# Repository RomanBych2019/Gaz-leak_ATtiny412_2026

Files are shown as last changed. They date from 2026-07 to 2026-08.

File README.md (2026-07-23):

# Контроллер датчика газа на ATtiny412

Назначение выводов:

- PA0: UPDI
- PA1: светодиод состояния платы
- PA2: вход АЦП датчика с внешней подтяжкой 4.7 кОм к GND
- PA3: отладочный TX, программный UART 2400 бод
- PA6: выход силового ключа 2
- PA7: выход силового ключа 1

Основная логика:

- после прогрева выполняется первоначальная калибровка чистого воздуха;
- новое значение сравнивается с сохраненным в EEPROM: если разница не больше допустимой, оно применяется и записывается; если разница большая, используется сохраненное значение;
- обрыв датчика или замыкание линии на GND определяется по АЦП около 0 В;
- замыкание выхода датчика на питание определяется по АЦП около +5 В;
- состояние ALARM защелкивается до перезапуска питания контроллера;
- остальные состояния являются восстанавливаемыми.

Автокалибровку можно отключить на этапе компиляции в `src/main.cpp`:

```cpp
#define AUTOCALIBR 0
```

При отключенной автокалибровке используются фиксированные заводские пороги АЦП.

Для выбора поведения PA6/PA7 измените `SENSOR_MODIFICATION` в `src/main.cpp`.

Варианты сборки:

- `attiny412`: распиновка базовой платы;
- `attiny412_lin`: распиновка платы с LIN-драйвером, сборка с `LIN_DRIVER`.

Сборка:

```sh
pio run -e attiny412
pio run -e attiny412_lin
```

Прошивка:

Проект использует `serialupdi`. Скорость загрузки задана в `platformio.ini`:
`upload_speed = 19200`.

Обычная версия:

```sh
pio run -e attiny412 -t upload
```

LIN-версия:

```sh
pio run -e attiny412_lin -t upload
```

Если программатор не определяется автоматически, укажите порт в `platformio.ini`:

```ini
upload_port = /dev/cu.usbserial-4
```

LIN-вариант:

- трансивер: TLIN2029ADRBRQ1;
- скорость обмена: 19200 бод;

- PA0: UPDI
- PA1: LIN TXD
- PA2: LIN RXD 
- PA3: светодиод состояния платы/отладочный TX, программный UART 2400 бод
- PA6: вход АЦП датчика с внешней подтяжкой 4.7 кОм к GND
- PA7: выход силового ключа

- статусный кадр: LIN ID `0x12`, PID `0x92`, enhanced checksum;
- данные ответа: `state`, `flags`, `adc_l`, `adc_h`;
- `flags`: bit0 = ALARM защелкнут, bit1 = выход PA7 активен, bit2 = неисправность датчика, bit3 = прогрев.

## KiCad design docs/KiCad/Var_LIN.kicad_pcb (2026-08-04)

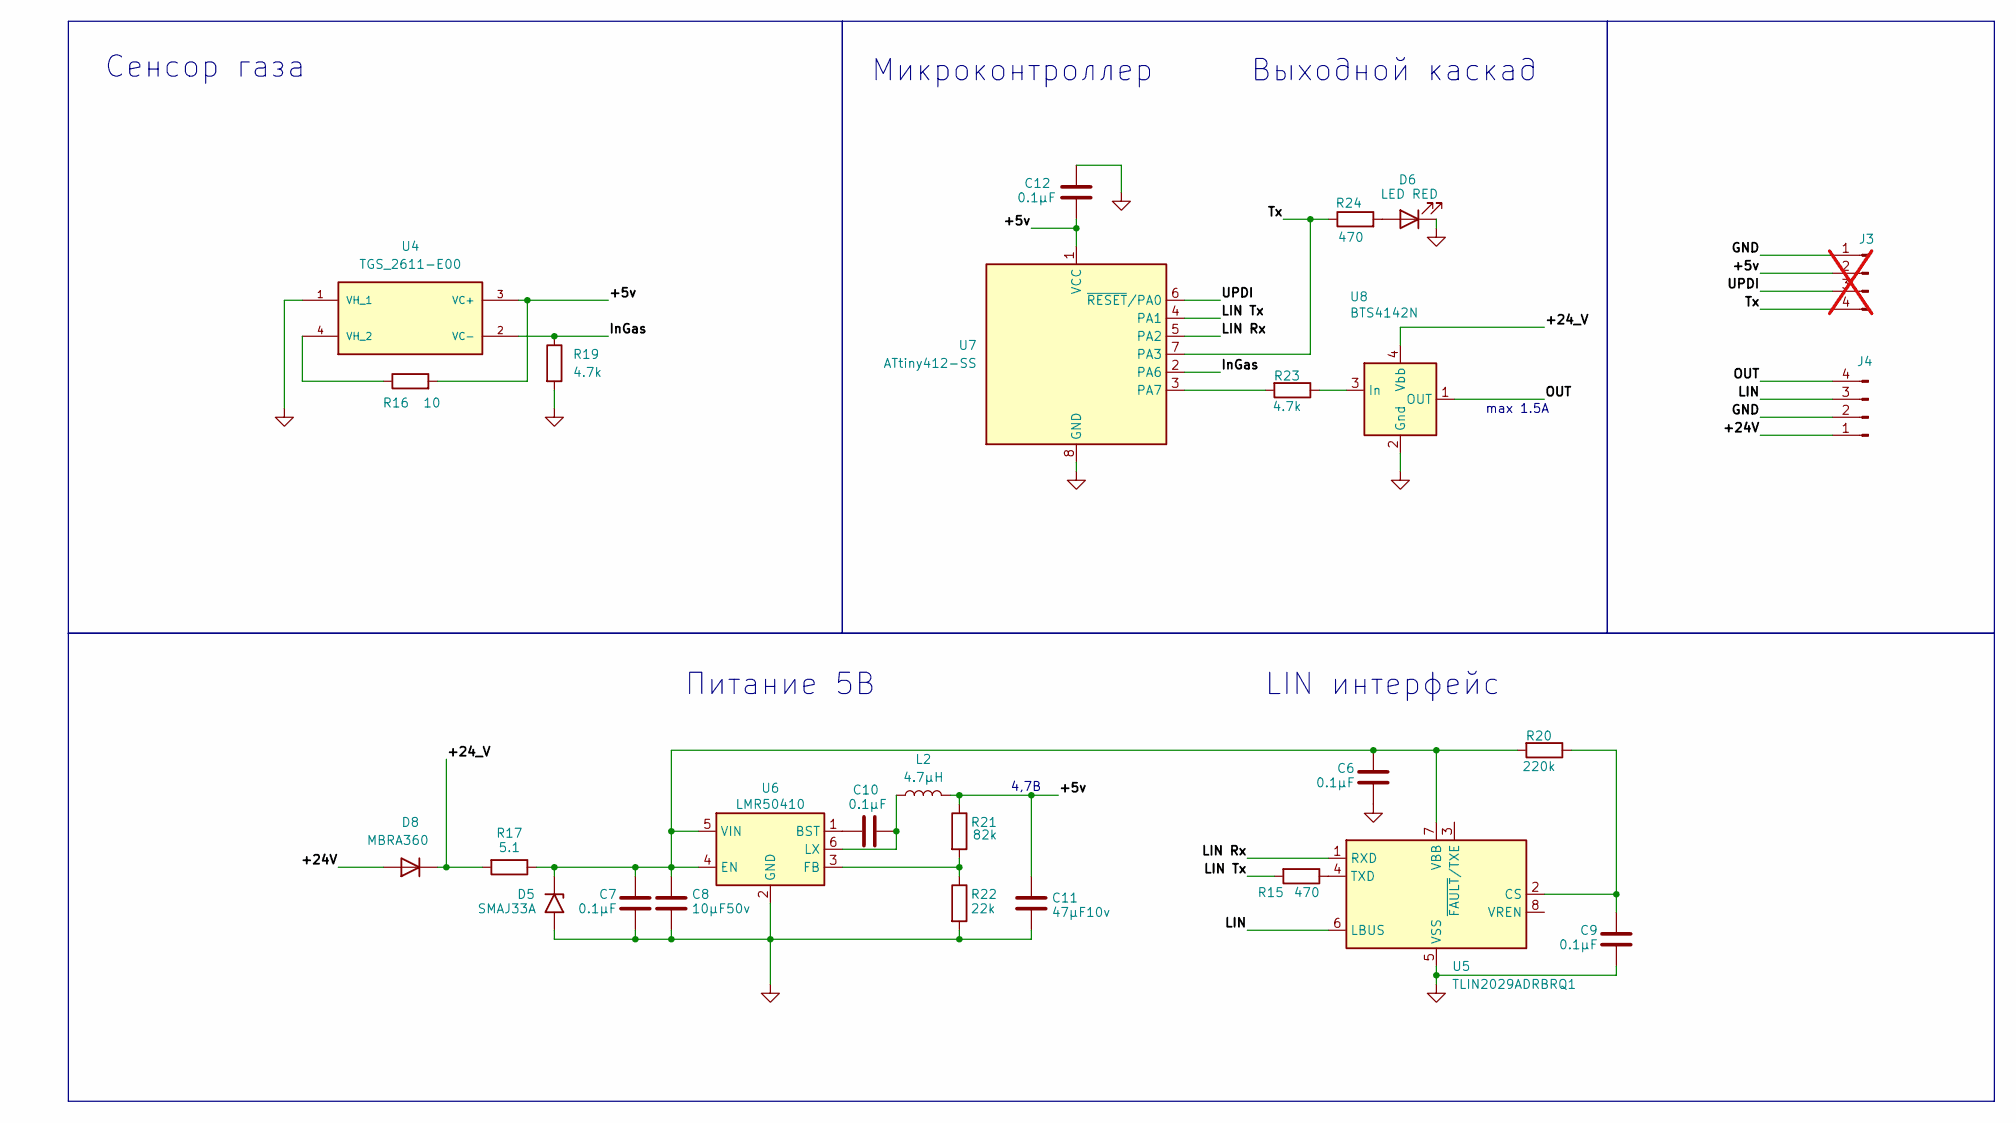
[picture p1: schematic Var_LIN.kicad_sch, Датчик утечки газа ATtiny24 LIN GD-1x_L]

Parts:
C6, C7, C9, C10, C12: 0.1µF; C_0603_1608Metric
C8: 10µF50v; C_0805_2012Metric
C11: 47µF10v; C_0805_2012Metric
D5: SMAJ33A; D_SMA
D6: LED RED; LED_0805_2012Metric
D8: MBRA360; D_SMA
J3: Conn_01x04_Pin; PinHeader_1x04_P1.27mm_Vertical; not fitted
J4: Conn_01x04_Pin; AMP SEAL 3.00mm_4p
L2: 4.7µH; L_1210_3225Metric
R15, R24: 470; R_0603_1608Metric
R16: 10; R_0805_2012Metric
R17: 5.1; R_1206_3216Metric
R19, R23: 4.7k; R_0603_1608Metric
R20: 220k; R_0603_1608Metric
R21: 82k; R_0603_1608Metric
R22: 22k; R_0603_1608Metric
U4: TGS_2611-E00; TO180P920X780-4P; PARTREV 0718
U5: TLIN2029ADRBRQ1; VSON-8-1EP_3x3mm_P0.65mm_EP1.65x2.4mm
U6: LMR50410; SOT-23-6
U7: ATtiny412-SS; SOIC-8_3.9x4.9mm_P1.27mm
U8: BTS4142N; SOT-223

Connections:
/+5v: C11.1, C12.2, J3.2, L2.2, R16.2, R21.1, U4.3 (VC+), U7.1 (VCC)
/+24V: D8.2 (A), J4.1; also elsewhere on the board
/+24_V: D8.1 (K), R17.2, U8.4 (Vbb)
/InGas: R19.1, U4.2 (VC-), U7.2 (PA6)
/LIN: J4.3, U5.6 (LBUS); also elsewhere on the board
/LIN Rx: U5.1 (RXD), U7.5 (PA2)
/LIN Tx: R15.2, U7.4 (PA1)
/OUT: J4.4, U8.1 (OUT), U8.5 (OUT); also elsewhere on the board
/Tx: J3.4, R24.1, U7.7 (PA3)
/UPDI: J3.3, U7.6 (~RESET/PA0)
GND: C6.2, C7.2, C8.2, C9.2, C11.2, C12.1, D5.2 (A2), D6.1 (K), J3.1, J4.2, R19.2, R22.2, U4.1 (VH_1), U5.5 (VSS), U6.2 (GND), U7.8 (GND), U8.2 (Gnd); also elsewhere on the board
unnamed: C6.1, C7.1, C8.1, D5.1 (A1), R17.1, R20.2, U5.7 (VBB), U6.4 (EN), U6.5 (VIN)
unnamed: D6.2 (A), R24.2
unnamed: R16.1, U4.4 (VH_2)
unnamed: C9.1, R20.1, U5.2 (CS)
unnamed: R15.1, U5.4 (TXD)
unnamed: C10.2, U6.1 (BST)
unnamed: R21.2, R22.1, U6.3 (FB)
unnamed: C10.1, L2.1, U6.6 (LX)
unnamed: R23.2, U7.3 (PA7)
unnamed: R23.1, U8.3 (In)

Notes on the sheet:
Сенсор газа
max 1.5A
4,7В
Микроконтроллер Выходной каскад
Питание 5В LIN интерфейс

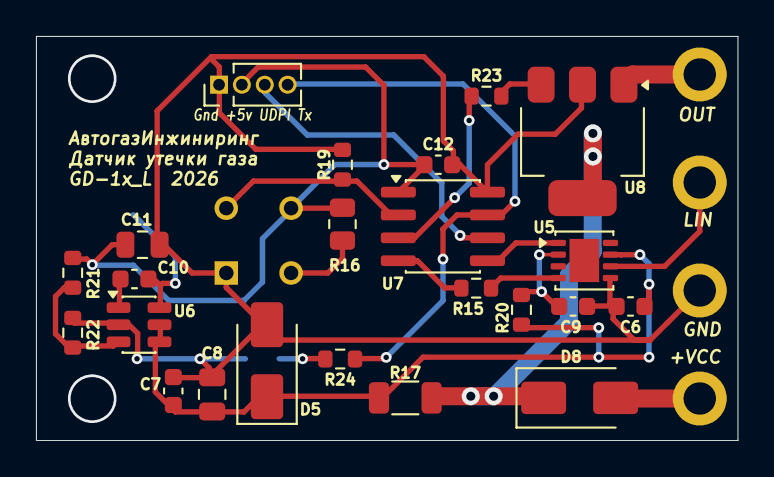
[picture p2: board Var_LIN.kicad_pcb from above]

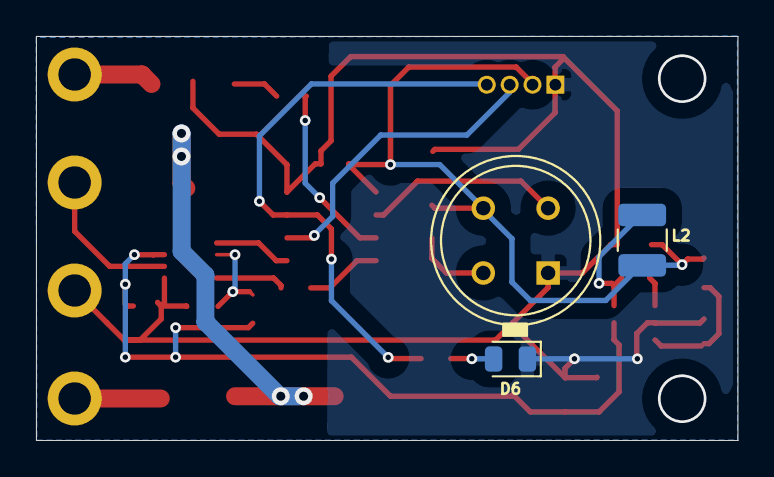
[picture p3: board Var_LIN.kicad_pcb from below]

Board: 2 copper layers, 39.0 x 22.4 mm, 27 parts (3 on the bottom side), 21 nets.

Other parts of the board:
J2: Conn_01x04_Pin; AMP SEAL 3.00mm_4p

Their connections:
/+24V: J2.1; also elsewhere on the board
/LIN: J2.3; also elsewhere on the board
/OUT: J2.4; also elsewhere on the board
GND: J2.2; also elsewhere on the board

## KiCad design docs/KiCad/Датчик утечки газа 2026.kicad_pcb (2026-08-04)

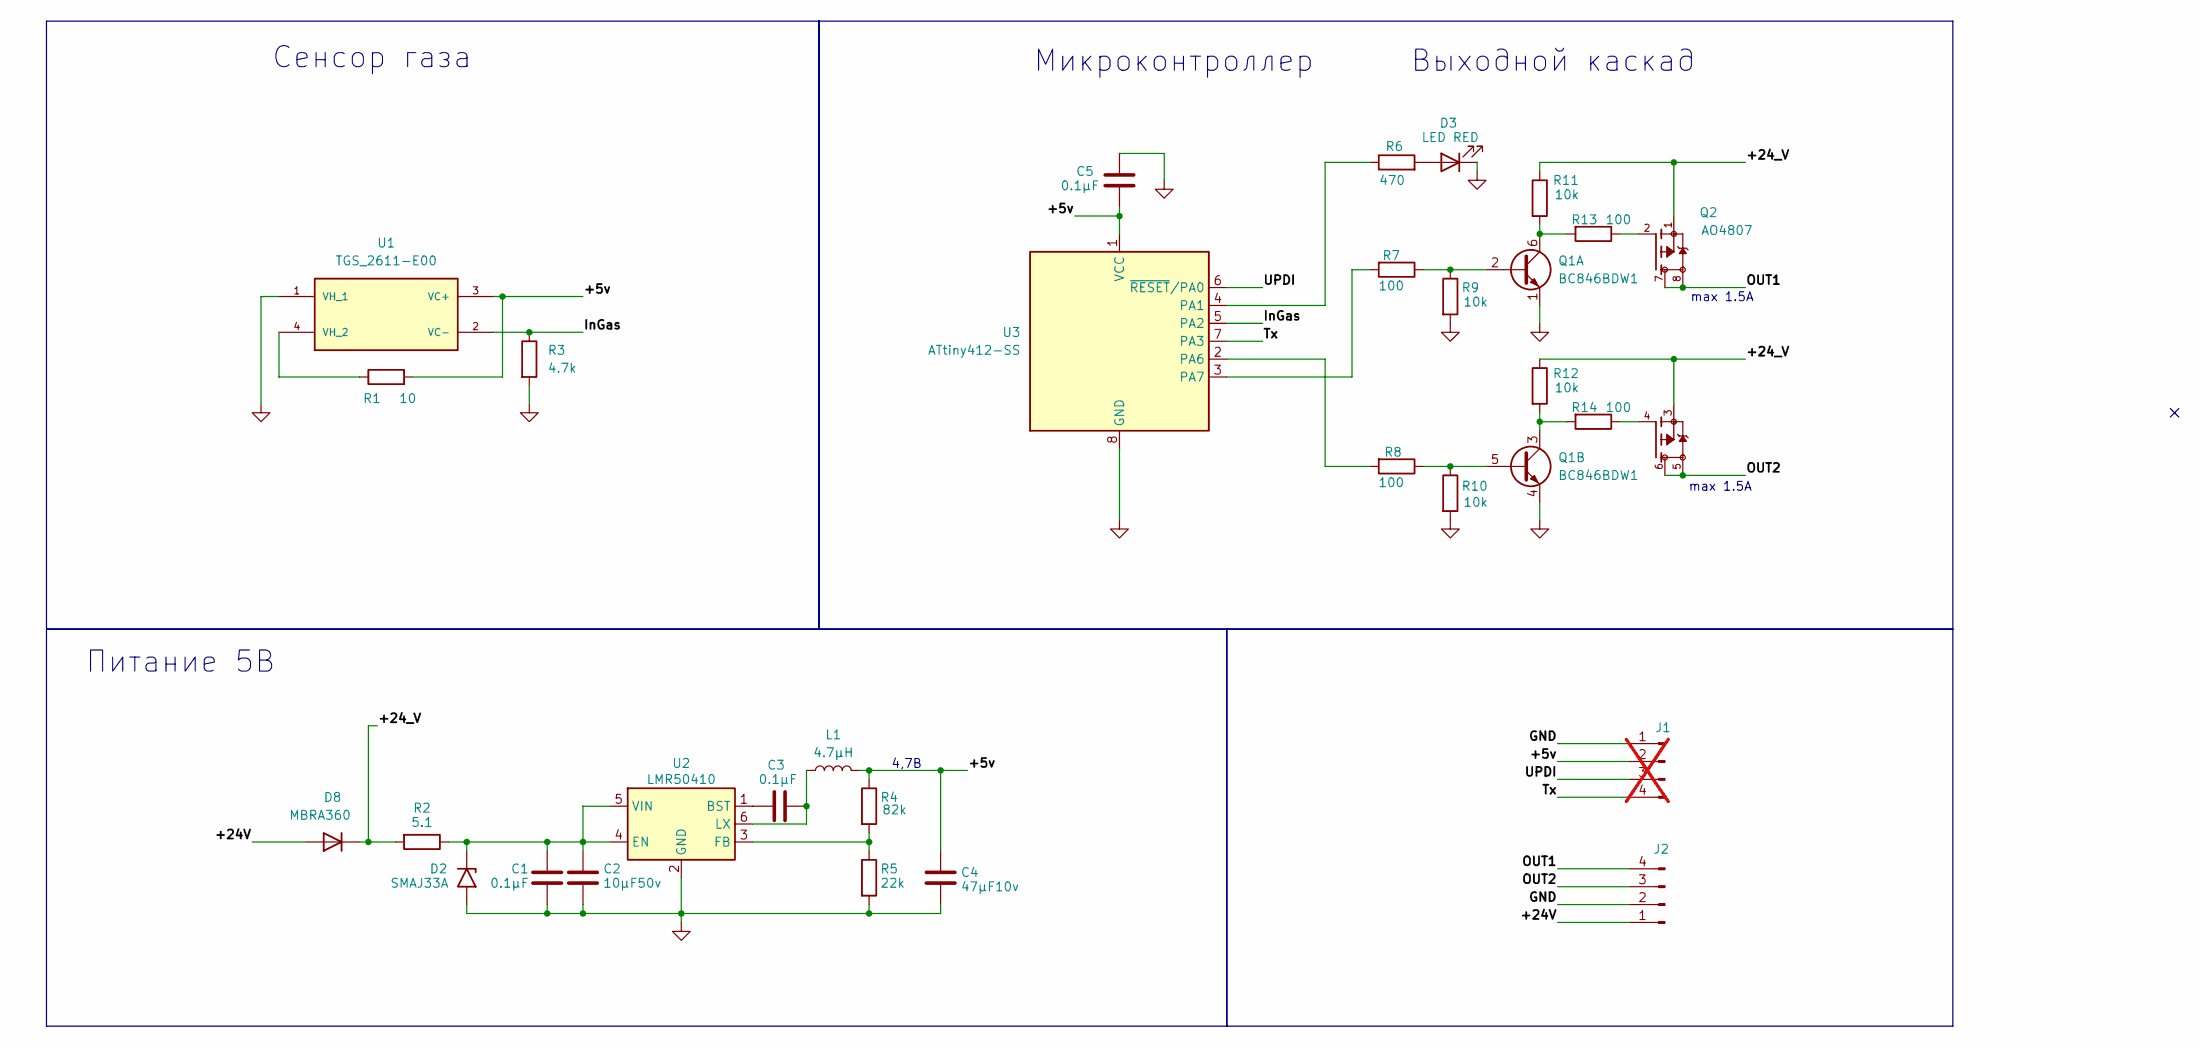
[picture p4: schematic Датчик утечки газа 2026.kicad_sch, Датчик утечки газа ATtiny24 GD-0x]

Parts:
C1, C3, C5: 0.1µF; C_0603_1608Metric
C2: 10µF50v; C_0805_2012Metric
C4: 47µF10v; C_0805_2012Metric
D2: SMAJ33A; D_SMA
D3: LED RED; LED_0805_2012Metric
D8: MBRA360; D_SMA
J1: Conn_01x04_Pin; PinHeader_1x04_P1.27mm_Vertical; not fitted
J2: Conn_01x04_Pin; AMP SEAL 3.00mm_4p
L1: 4.7µH; L_1210_3225Metric
Q1: BC846BDW1; SOT-363_SC-70-6
Q2: AO4807; SOIC-8_3.9x4.9mm_P1.27mm; PARTREV I
R1: 10; R_0805_2012Metric
R2: 5.1; R_1206_3216Metric
R3: 4.7k; R_0603_1608Metric
R4: 82k; R_0603_1608Metric
R5: 22k; R_0603_1608Metric
R6: 470; R_0603_1608Metric
R7, R8, R13, R14: 100; R_0603_1608Metric
R9, R10, R11, R12: 10k; R_0603_1608Metric
U1: TGS_2611-E00; TO180P920X780-4P; PARTREV 0718
U2: LMR50410; SOT-23-6
U3: ATtiny412-SS; SOIC-8_3.9x4.9mm_P1.27mm

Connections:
/+5v: C4.1, C5.2, J1.2, L1.2, R1.2, R4.1, U1.3 (VC+), U3.1 (VCC); also elsewhere on the board
/+24V: D8.2 (A), J2.1
/+24_V: D8.1 (K), Q2.1, Q2.3, R2.2, R11.1, R12.1
/InGas: R3.1, U1.2 (VC-), U3.5 (PA2); also elsewhere on the board
/OUT1: J2.4, Q2.7, Q2.8
/OUT2: J2.3, Q2.5, Q2.6
/Tx: J1.4, U3.7 (PA3)
/UPDI: J1.3, U3.6 (~RESET/PA0)
GND: C1.2, C2.2, C4.2, C5.1, D2.2 (A2), D3.1 (K), J1.1, J2.2, Q1.1 (E1), Q1.4 (E2), R3.2, R5.2, R9.2, R10.2, U1.1 (VH_1), U2.2 (GND), U3.8 (GND); also elsewhere on the board
unnamed: C1.1, C2.1, D2.1 (A1), R2.1, U2.4 (EN), U2.5 (VIN)
unnamed: D3.2 (A), R6.2
unnamed: Q1.2 (B1), R7.1, R9.1
unnamed: Q1.6 (C1), R11.2, R13.2
unnamed: Q1.5 (B2), R8.1, R10.1
unnamed: Q1.3 (C2), R12.2, R14.2
unnamed: Q2.2, R13.1
unnamed: Q2.4, R14.1
unnamed 17: R1.1, U1.4 (VH_2); also elsewhere on the board
unnamed: C3.2, U2.1 (BST)
unnamed: R4.2, R5.1, U2.3 (FB)
unnamed: C3.1, L1.1, U2.6 (LX)
unnamed: R6.1, U3.4 (PA1)
unnamed: R8.2, U3.2 (PA6)
unnamed: R7.2, U3.3 (PA7)

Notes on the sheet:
4,7В
max 1.5A
Сенсор газа
Микроконтроллер Выходной каскад
Питание 5В

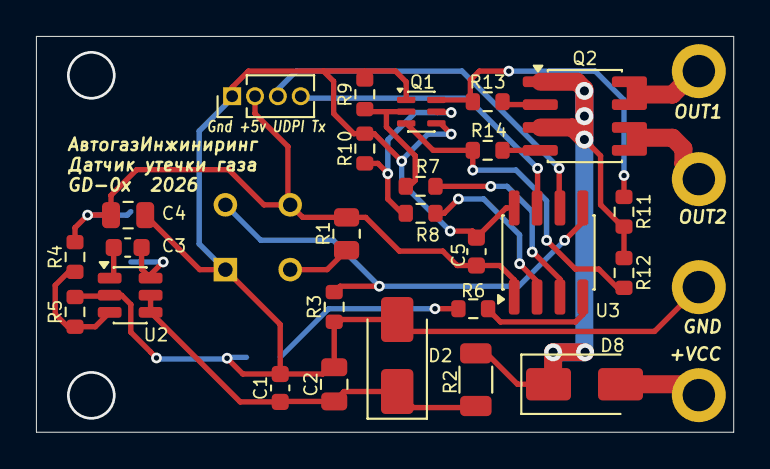
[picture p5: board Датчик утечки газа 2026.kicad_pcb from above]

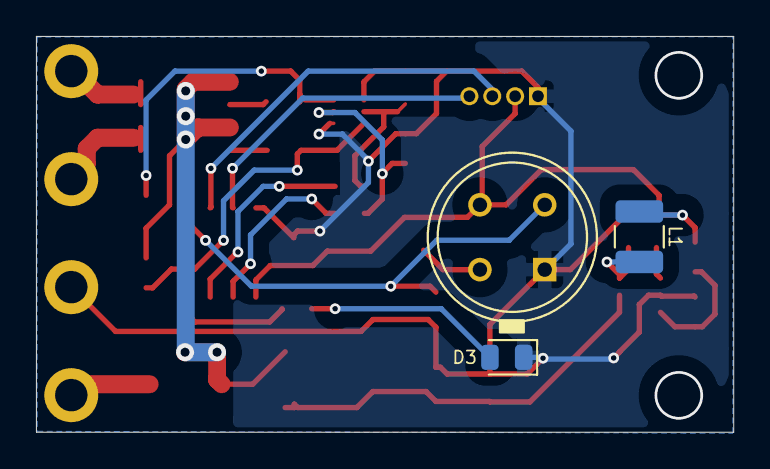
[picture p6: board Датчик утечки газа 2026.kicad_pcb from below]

Board: 2 copper layers, 38.7 x 22.0 mm, 30 parts (3 on the bottom side), 24 nets.

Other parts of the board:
U4: TGS_2611-E00; TO180P920X780-4P

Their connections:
/+5v: U4.3 (VC+); also elsewhere on the board
/InGas: U4.2 (VC-); also elsewhere on the board
GND: U4.1 (VH_1); also elsewhere on the board
unnamed 17: U4.4 (VH_2); also elsewhere on the board

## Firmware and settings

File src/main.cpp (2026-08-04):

#include <Arduino.h>

#ifndef AUTOCALIBR
#define AUTOCALIBR 1
#endif

#if AUTOCALIBR
#include <avr/eeprom.h>
#endif

// ============================================================
// Контроллер датчика газа на ATtiny412
// ============================================================
// PA0 - UPDI, не использовать как GPIO
// PA1 - светодиод состояния платы                | LIN TX в версии LIN_DRIVER
// PA2 - вход АЦП датчика                         | LIN RX в версии LIN_DRIVER
// PA3 - отладочный TX, программный UART 9600 бод | светодиод состояния платы в
// версии LIN_DRIVER PA6 - выход силового ключа 2                   | вход АЦП
// датчика в версии LIN_DRIVER PA7 - выход силового ключа 1                   |
// единственный активный выход в версии LIN_DRIVER
//
// Логика:
// - напряжение датчика проверяется по заводским или откалиброванным порогам АЦП
// - АЦП около 0 В: датчик оборван или линия датчика подключена к GND
// - АЦП около +5 В: выход датчика замкнут на VCC
// - состояние ALARM защелкивается в RAM и сбрасывается только отключением
// питания
// - остальные состояния могут вернуться в NORMAL, когда АЦП вернется в
// допустимый диапазон
// ============================================================

#ifndef DEBUG
#define DEBUG 0
#endif

#ifndef LIN_DRIVER
#define LIN_DRIVER 0
#endif

#if LIN_DRIVER
#define LED_PIN PIN_PA3
#define SENSOR_PIN PIN_PA6
#define DEBUG_TX_PIN PIN_PA3
#define KEY_PIN PIN_PA7
#define LIN_RX_PIN PIN_PA2
#define LIN_TX_PIN PIN_PA1
#else
#define LED_PIN PIN_PA1
#define SENSOR_PIN PIN_PA2
#define DEBUG_TX_PIN PIN_PA3
#define KEY1_PIN PIN_PA7
#define KEY2_PIN PIN_PA6
#endif

#if DEBUG && LIN_DRIVER
// В LIN-версии PA3 используется светодиодом, но при DEBUG приоритет у
// отладочного TX на PA3, поэтому индикация светодиодом отключается.
#define LED_ENABLED 0
#else
#define LED_ENABLED 1
#endif

// ============================================================
// Отладочный программный UART на PA3
// ============================================================

#if DEBUG

const uint32_t DEBUG_BAUD = 2400;
const uint16_t BIT_TIME_US = (1000000UL / DEBUG_BAUD);

void debugTxWriteBit(bool bitValue) {
  digitalWrite(DEBUG_TX_PIN, bitValue ? HIGH : LOW);
  delayMicroseconds(BIT_TIME_US);
}

void debugTxWriteByte(uint8_t b) {
  noInterrupts();

  // Стартовый бит
  debugTxWriteBit(false);

  // Биты данных, младший бит первым
  for (uint8_t i = 0; i < 8; i++) {
    debugTxWriteBit(b & 0x01);
    b >>= 1;
  }

  // Стоповый бит
  debugTxWriteBit(true);

  interrupts();
}

void debugPrint(const char *s) {
  while (*s) {
    debugTxWriteByte((uint8_t)*s++);
  }
}

void debugPrintln(const char *s) {
  debugPrint(s);
  debugPrint("\r\n");
}

void debugPrintUint(uint32_t value) {
  char buf[12];
  ultoa(value, buf, 10);
  debugPrint(buf);
}
#endif

// ============================================================
// Основные настройки
// ============================================================

// АЦП в Arduino analogRead() 10-битный: 0...1023
const uint16_t ADC_MAX_VALUE = 1023;

// Время прогрева датчика после включения питания.
const uint32_t SENSOR_WARMUP_MS = 45000UL;

// Период отладочного вывода
const uint32_t DEBUG_PERIOD_MS = 5000UL;

// Время подтверждения тревоги по газу.
// ALARM защелкивается, только если газовый порог непрерывно превышен
// в течение этого времени.
const uint32_t ALARM_CONFIRM_MS = 3000UL;

// Время подтверждения неисправности датчика по мин./макс. напряжению
const uint32_t FAULT_CONFIRM_MS = 1000UL;

// Время выхода из неисправности датчика.
// Состояния FAULT могут вернуться в NORMAL, когда АЦП вернется в допустимый
// диапазон.
const uint32_t FAULT_RELEASE_MS = 1000UL;

// Усреднение АЦП
const uint8_t ADC_SAMPLES = 16;

// Коэффициент ФНЧ для АЦП.
// 8 означает: filtered = filtered * 7/8 + raw * 1/8
const uint8_t FILTER_DIV = 8;

// ============================================================
// Газовые пороги
// ============================================================

// true  - сигнал АЦП увеличивается при наличии газа
// false - сигнал АЦП уменьшается при наличии газа
const bool SENSOR_SIGNAL_INCREASES_WITH_GAS = true;

// Порог включения тревоги по газу без автокалибровки
const uint16_t GAS_ALARM_ON_ADC = 600;

// Базовый уровень чистого воздуха для заводских порогов.
// При автокалибровке пороги сдвигаются на разницу между измеренным
// чистым воздухом и этим значением.
// 0.3 В при VCC = 5 В: 0.3 / 5.0 * 1023 ~= 61.
const uint16_t GAS_CLEAN_AIR_FACTORY_ADC = 61;

// Порог выключения тревоги по газу больше не используется для сброса ALARM,
// потому что ALARM защелкивается до отключения питания.
// Оставлен только для возможных будущих вариантов без защелкивания.
const uint16_t GAS_ALARM_OFF_ADC = 550;

#if AUTOCALIBR
// Максимально допустимая разница между новой калибровкой и сохраненной.
// Если разница больше, считаем, что запуск выполнен в газовой среде,
// и используем значение из EEPROM.
const uint16_t AUTOCALIBR_MAX_DELTA_ADC = 60;

const uint16_t AUTOCALIBR_EEPROM_SIGNATURE = 0x4743; // 'G''C'
const uint8_t AUTOCALIBR_EEPROM_ADDR = 0;
#endif

// ============================================================
// Диагностические пороги напряжения датчика
// ============================================================
//
// На входе датчика SENSOR_PIN установлена внешняя подтяжка 4.7 кОм к GND.
//
// ADC <= ADC_SENSOR_OPEN_OR_GND_ON:
//   датчик оборван или линия датчика подключена к GND.
//   напряжение на SENSOR_PIN около 0 В.
//
// ADC >= ADC_SENSOR_SHORT_TO_VCC_ON:
//   выход датчика замкнут на питание.
//   напряжение на SENSOR_PIN около +5 В.
//
// Пороги OFF задают гистерезис для возврата из состояний неисправности.

const uint16_t ADC_SENSOR_OPEN_OR_GND_ON = 20;
const uint16_t ADC_SENSOR_OPEN_OR_GND_OFF = 50;

const uint16_t ADC_SENSOR_SHORT_TO_VCC_ON = 1000;
const uint16_t ADC_SENSOR_SHORT_TO_VCC_OFF = 970;

// Приблизительные значения при VCC = 5 В:
// ADC 20   ~= 0.10 V
// ADC 50   ~= 0.24 V
// ADC 970  ~= 4.74 V
// ADC 1000 ~= 4.89 V

// ============================================================
// LIN interface
// ============================================================
//
// TLIN2029ADRBRQ1 - это физический LIN-трансивер. Протокол LIN
// обслуживает ATtiny412 через USART0:
// - TXD трансивера <- PA1 / LIN_TX_PIN
// - RXD трансивера -> PA2 / LIN_RX_PIN
//
// Узел работает как LIN slave и отвечает на header с PID 0x92
// (LIN ID 0x12) статусным кадром:
// byte 0: SystemState
// byte 1: flags, bit0=alarmLatched, bit1=outputActive, bit2=fault, bit3=warmup
// byte 2: filteredAdc low byte
// byte 3: filteredAdc high byte

#if LIN_DRIVER
const uint32_t LIN_BAUD = 19200UL;
const uint8_t LIN_STATUS_ID = 0x12;
const uint8_t LIN_STATUS_DATA_LEN = 4;
const uint8_t LIN_HEADER_TIMEOUT_MS = 10;

enum LinRxState { LIN_WAIT_SYNC, LIN_WAIT_PID };

LinRxState linRxState = LIN_WAIT_SYNC;
uint32_t lastLinByteMs = 0;
#endif

// ============================================================
// Состояния системы
// ============================================================

enum SystemState {
  STATE_WARMUP,             // датчик прогревается после включения питания
  STATE_NORMAL,             // датчик исправен, газовый порог не превышен
  STATE_ALARM,              // датчик исправен, газовый порог превышен
  STATE_SENSOR_OPEN_OR_GND, // датчик оборван
  STATE_SENSOR_SHORT_TO_VCC // выход датчика замкнут на питание
};

SystemState systemState = STATE_WARMUP;

uint16_t filteredAdc = 0;
uint16_t activeGasAlarmOnAdc = GAS_ALARM_ON_ADC;
uint16_t activeGasAlarmOffAdc = GAS_ALARM_OFF_ADC;

// Защелка ALARM. Хранится в RAM, поэтому сбрасывается после отключения питания.
// Примечание: аппаратный сброс или сброс watchdog также очищает RAM при обычном
// старте.
bool alarmLatched = false;

struct OutputState {
#if !LIN_DRIVER
  bool key1;
  bool key2;
#else
  bool key;
#endif
};

#if !LIN_DRIVER

// ============================================================
// Варианты поведения PA6 / PA7
// ============================================================
//
// MOD_SINGLE_HIGH:
//   NORMAL       PA6=0, PA7=0
//   ALARM        PA6=0, PA7=1
//
// MOD_SINGLE_LOW:
//   NORMAL       PA6=0, PA7=1
//   ALARM        PA6=0, PA7=0
//
// MOD_DUAL_HIGH:
//   NORMAL       PA6=0, PA7=0
//   ALARM        PA6=1, PA7=1
//
// MOD_COMPLEMENTARY:
//   NORMAL       PA6=1, PA7=0
//   ALARM        PA6=0, PA7=1
//
// MOD_ACTIVE_LOW:
//   NORMAL       PA6=1, PA7=1
//   ALARM        PA6=0, PA7=0
//
// Во время WARMUP PA6/PA7 в NORMAL.

enum SensorModification {
  MOD_SINGLE_HIGH, // ключ OUT1 с активным высоким уровнем, высокий уровень на
                   // выходе при ALARM, OUT2 неиспользуется, выключен
  MOD_SINGLE_LOW, // ключ OUT1 с активным низким уровнем, низкий уровень на
                  // выходе при ALARM, OUT2 неиспользуется, выключен
  MOD_DUAL_HIGH, // ключи OUT1 и OUT2 с активным высоким уровнем, высокий
                 // уровень на обоих выходах при ALARM
  MOD_COMPLEMENTARY, // ключи OUT1 и OUT2 с активным высоким уровнем, при ALARM
                     // OUT1 включен, OUT2 выключен
  MOD_ACTIVE_LOW // ключи OUT1 и OUT2 с активным низким уровнем, низкий уровень
                 // на обоих выходах при ALARM
};

// ------------ ВЫБЕРИТЕ МОДИФИКАЦИЮ ДАТЧИКА ЗДЕСЬ ------------
const SensorModification SENSOR_MODIFICATION = MOD_DUAL_HIGH;
// -------------------------------------------------------------

const OutputState OUTPUT_SAFE_OFF = {false, false};

OutputState getOutputState(SystemState state) {
  // if (state == STATE_WARMUP ||
  //     state == STATE_SENSOR_OPEN_OR_GND ||
  //     state == STATE_SENSOR_SHORT_TO_VCC) {
  //   return OUTPUT_SAFE_OFF;
  // }

  bool alarm = (state == STATE_ALARM);

  if (state == STATE_WARMUP) {
    alarm = false;
  }

  if (state == STATE_SENSOR_OPEN_OR_GND || state == STATE_SENSOR_SHORT_TO_VCC) {
    return OUTPUT_SAFE_OFF;
  }

  switch (SENSOR_MODIFICATION) {
  case MOD_SINGLE_HIGH:
    if (alarm)
      return {true, false};
    else
      return {false, false};

  case MOD_SINGLE_LOW:
    if (alarm)
      return {false, false};
    else
      return {true, false};

  case MOD_DUAL_HIGH:
    if (alarm)
      return {true, true};
    else
      return {false, false};

  case MOD_COMPLEMENTARY:
    if (alarm)
      return {true, false};
    else
      return {false, true};

  case MOD_ACTIVE_LOW:
    if (alarm)
      return {false, false};
    else
      return {true, true};

  default:
    return OUTPUT_SAFE_OFF;
  }
}

void applyOutputs(SystemState state) {
  OutputState out = getOutputState(state);

  digitalWrite(KEY1_PIN, out.key1 ? HIGH : LOW);
  digitalWrite(KEY2_PIN, out.key2 ? HIGH : LOW);
}

#else

// ============================================================
// Варианты поведения PA7
// ============================================================
//
// MOD_SINGLE_HIGH:
//   NORMAL       PA7=0
//   ALARM        PA7=1
//
// MOD_SINGLE_LOW:
//   NORMAL       PA7=1
//   ALARM        PA7=0
//
//

enum SensorModification {
  MOD_SINGLE_HIGH, // ключ OUT с активным высоким уровнем, высокий уровень на
                   // выходе при ALARM
  MOD_SINGLE_LOW // ключ OUT с активным низким уровнем, низкий уровень на выходе
                 // при ALARM
};

// ------------ ВЫБЕРИТЕ МОДИФИКАЦИЮ ДАТЧИКА ЗДЕСЬ ------------
const SensorModification SENSOR_MODIFICATION = MOD_SINGLE_HIGH;
// -------------------------------------------------------------

const OutputState OUTPUT_SAFE_OFF = {false};

OutputState getOutputState(SystemState state) {

  bool alarm = (state == STATE_ALARM);

  if (state == STATE_WARMUP) {
    alarm = false;
  }

  if (state == STATE_SENSOR_OPEN_OR_GND || state == STATE_SENSOR_SHORT_TO_VCC) {
    return OUTPUT_SAFE_OFF;
  }

  switch (SENSOR_MODIFICATION) {
  case MOD_SINGLE_HIGH:
    if (alarm)
      return {true};
    else
      return {false};

  case MOD_SINGLE_LOW:
    if (alarm)
      return {false};
    else
      return {true};

  default:
    return OUTPUT_SAFE_OFF;
  }
}

void applyOutputs(SystemState state) {
  OutputState out = getOutputState(state);
  digitalWrite(KEY_PIN, out.key ? HIGH : LOW);
}

#endif

// ============================================================
// LIN slave
// ============================================================

#if LIN_DRIVER

uint8_t linProtectedId(uint8_t id) {
  id &= 0x3F;

  uint8_t p0 = ((id >> 0) ^ (id >> 1) ^ (id >> 2) ^ (id >> 4)) & 0x01;
  uint8_t p1 = (~((id >> 1) ^ (id >> 3) ^ (id >> 4) ^ (id >> 5))) & 0x01;

  return id | (p0 << 6) | (p1 << 7);
}

bool linPidIsValid(uint8_t pid) { return linProtectedId(pid & 0x3F) == pid; }

uint8_t linChecksum(uint8_t pid, const uint8_t *data, uint8_t len) {
  uint16_t sum = pid;

  for (uint8_t i = 0; i < len; i++) {
    sum += data[i];
    if (sum > 0xFF) {
      sum = (sum & 0xFF) + 1;
    }
  }

  return (uint8_t)(~sum);
}

uint8_t linStateCode(SystemState state) { return (uint8_t)state; }

bool outputIsActive() {
  OutputState out = getOutputState(systemState);
  return out.key;
}

bool faultIsActive() {
  return systemState == STATE_SENSOR_OPEN_OR_GND ||
         systemState == STATE_SENSOR_SHORT_TO_VCC;
}

void linSendStatus(uint8_t pid) {
  uint8_t flags = 0;

  if (alarmLatched) {
    flags |= 0x01;
  }
  if (outputIsActive()) {
    flags |= 0x02;
  }
  if (faultIsActive()) {
    flags |= 0x04;
  }
  if (systemState == STATE_WARMUP) {
    flags |= 0x08;
  }

  uint8_t data[LIN_STATUS_DATA_LEN] = {linStateCode(systemState), flags,
                                       (uint8_t)(filteredAdc & 0xFF),
                                       (uint8_t)(filteredAdc >> 8)};

  Serial.write(data, LIN_STATUS_DATA_LEN);
  Serial.write(linChecksum(pid, data, LIN_STATUS_DATA_LEN));
  Serial.flush();
}

void linProcessByte(uint8_t b) {
  if (millis() - lastLinByteMs > LIN_HEADER_TIMEOUT_MS) {
    linRxState = LIN_WAIT_SYNC;
  }
  lastLinByteMs = millis();

  if (b == 0x00) {
    linRxState = LIN_WAIT_SYNC;
    return;
  }

  switch (linRxState) {
  case LIN_WAIT_SYNC:
    if (b == 0x55) {
      linRxState = LIN_WAIT_PID;
    }
    break;

  case LIN_WAIT_PID:
    linRxState = LIN_WAIT_SYNC;

    if (!linPidIsValid(b)) {
      return;
    }

    if (b == linProtectedId(LIN_STATUS_ID)) {
      linSendStatus(b);
    }
    break;
  }
}

void linService() {
  while (Serial.available() > 0) {
    int b = Serial.read();

    if (b >= 0) {
      linProcessByte((uint8_t)b);
    }
  }
}

void linBegin() {
  pinMode(LIN_TX_PIN, OUTPUT);
  pinMode(LIN_RX_PIN, INPUT_PULLUP);

  Serial.swap(1);
  Serial.begin(LIN_BAUD, SERIAL_8N1);
}

#endif

void serviceDelay(uint16_t delayMs) {
#if LIN_DRIVER
  uint32_t startMs = millis();

  while (millis() - startMs < delayMs) {
    linService();
    delay(1);
  }
#else
  delay(delayMs);
#endif
}

// ============================================================
// ADC
// ============================================================

uint16_t readAdcAverage() {
  uint32_t sum = 0;

  for (uint8_t i = 0; i < ADC_SAMPLES; i++) {
    sum += analogRead(SENSOR_PIN);
    serviceDelay(2);
  }

  return sum / ADC_SAMPLES;
}

// ============================================================
// Логика газового порога
// ============================================================

bool isAlarmOnLevel(uint16_t adc) {
  if (SENSOR_SIGNAL_INCREASES_WITH_GAS) {
    return adc >= activeGasAlarmOnAdc;
  } else {
    return adc <= activeGasAlarmOnAdc;
  }
}

bool isAlarmOffLevel(uint16_t adc) {
  if (SENSOR_SIGNAL_INCREASES_WITH_GAS) {
    return adc <= activeGasAlarmOffAdc;
  } else {
    return adc >= activeGasAlarmOffAdc;
  }
}

// ============================================================
// Логика уровней неисправности датчика
// ============================================================

bool isSensorOpenOrGndOn(uint16_t adc) {
  return adc <= ADC_SENSOR_OPEN_OR_GND_ON;
}

bool isSensorOpenOrGndOff(uint16_t adc) {
  return adc >= ADC_SENSOR_OPEN_OR_GND_OFF;
}

bool isSensorShortToVccOn(uint16_t adc) {
  return adc >= ADC_SENSOR_SHORT_TO_VCC_ON;
}

bool isSensorShortToVccOff(uint16_t adc) {
  return adc <= ADC_SENSOR_SHORT_TO_VCC_OFF;
}

// ============================================================
// Автокалибровка чистого воздуха
// ============================================================

#if AUTOCALIBR

uint16_t adcAbsDiff(uint16_t a, uint16_t b) {
  return (a >= b) ? (a - b) : (b - a);
}

uint16_t clampAdc(int16_t adc) {
  if (adc < 0) {
    return 0;
  }

  if (adc > ADC_MAX_VALUE) {
    return ADC_MAX_VALUE;
  }

  return (uint16_t)adc;
}

uint8_t autocalibrChecksum(uint16_t cleanAirAdc) {
  return (uint8_t)(0xA5 ^ (AUTOCALIBR_EEPROM_SIGNATURE & 0xFF) ^
                   (AUTOCALIBR_EEPROM_SIGNATURE >> 8) ^ (cleanAirAdc & 0xFF) ^
                   (cleanAirAdc >> 8));
}

uint16_t eepromReadUint16(uint8_t addr) {
  return (uint16_t)eeprom_read_byte((const uint8_t *)addr) |
         ((uint16_t)eeprom_read_byte((const uint8_t *)(addr + 1)) << 8);
}

void eepromUpdateUint16(uint8_t addr, uint16_t value) {
  eeprom_update_byte((uint8_t *)addr, (uint8_t)(value & 0xFF));
  eeprom_update_byte((uint8_t *)(addr + 1), (uint8_t)(value >> 8));
}

bool loadCalibration(uint16_t &cleanAirAdc) {
  uint16_t signature = eepromReadUint16(AUTOCALIBR_EEPROM_ADDR);
  uint16_t storedAdc = eepromReadUint16(AUTOCALIBR_EEPROM_ADDR + 2);
  uint8_t storedChecksum =
      eeprom_read_byte((const uint8_t *)(AUTOCALIBR_EEPROM_ADDR + 4));

  if (signature != AUTOCALIBR_EEPROM_SIGNATURE || storedAdc > ADC_MAX_VALUE ||
      storedChecksum != autocalibrChecksum(storedAdc)) {
    return false;
  }

  cleanAirAdc = storedAdc;
  return true;
}

void saveCalibration(uint16_t cleanAirAdc) {
  eepromUpdateUint16(AUTOCALIBR_EEPROM_ADDR, AUTOCALIBR_EEPROM_SIGNATURE);
  eepromUpdateUint16(AUTOCALIBR_EEPROM_ADDR + 2, cleanAirAdc);
  eeprom_update_byte((uint8_t *)(AUTOCALIBR_EEPROM_ADDR + 4),
                     autocalibrChecksum(cleanAirAdc));
}

void applyCalibration(uint16_t cleanAirAdc) {
  int16_t alarmOnOffset =
      (int16_t)GAS_ALARM_ON_ADC - (int16_t)GAS_CLEAN_AIR_FACTORY_ADC;
  int16_t alarmOffOffset =
      (int16_t)GAS_ALARM_OFF_ADC - (int16_t)GAS_CLEAN_AIR_FACTORY_ADC;

  activeGasAlarmOnAdc = clampAdc((int16_t)cleanAirAdc + alarmOnOffset);
  activeGasAlarmOffAdc = clampAdc((int16_t)cleanAirAdc + alarmOffOffset);
}

void runInitialCalibration(uint16_t warmupAdc) {
  if (isSensorOpenOrGndOn(warmupAdc) || isSensorShortToVccOn(warmupAdc)) {
    return;
  }

  uint16_t storedCleanAirAdc = 0;
  bool hasStoredCalibration = loadCalibration(storedCleanAirAdc);
  uint16_t selectedCleanAirAdc = warmupAdc;
  bool writeCalibration = false;

  if (hasStoredCalibration) {
    if (adcAbsDiff(warmupAdc, storedCleanAirAdc) <= AUTOCALIBR_MAX_DELTA_ADC) {
      selectedCleanAirAdc = warmupAdc;
      writeCalibration = (warmupAdc != storedCleanAirAdc);
    } else {
      selectedCleanAirAdc = storedCleanAirAdc;
    }
  } else {
    writeCalibration = true;
  }

  applyCalibration(selectedCleanAirAdc);

  if (writeCalibration) {
    saveCalibration(selectedCleanAirAdc);
  }

#if DEBUG
  debugPrint("Calibration clean_air=");
  debugPrintUint(selectedCleanAirAdc);
  debugPrint("  gas_on=");
  debugPrintUint(activeGasAlarmOnAdc);
  debugPrint(writeCalibration ? "  saved" : "  kept");
  debugPrint("\r\n");
#endif
}
#endif

// ============================================================
// Индикация светодиодом
// ============================================================
//
// В базовой версии светодиод на PA1. В LIN-версии светодиод на PA3,
// но при DEBUG он отключается, потому что PA3 используется как отладочный TX.
//
// WARMUP              - короткая вспышка раз в секунду
// NORMAL              - короткая вспышка раз в 2 секунды
// ALARM               - частое мигание, защелкнуто до отключения питания
// SENSOR_OPEN_OR_GND  - две вспышки, пауза
// SENSOR_SHORT_TO_VCC - три вспышки, пауза

void ledSet(bool on) {
#if LED_ENABLED
  digitalWrite(LED_PIN, on ? HIGH : LOW);
#else
  (void)on;
#endif
}
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
void loop() {
  uint16_t adcRaw = readAdcAverage();

  filteredAdc =
      ((uint32_t)filteredAdc * (FILTER_DIV - 1) + adcRaw) / FILTER_DIV;

  // ----------------------------------------------------------
  // Если ALARM защелкнут, он не может вернуться в NORMAL.
  // Сброс только снятием питания с контроллера.
  // Остальные состояния могут вернуться в NORMAL.
  // ----------------------------------------------------------
  if (alarmLatched) {
    setState(STATE_ALARM);
  } else {
    // Сначала обработать диагностические состояния напряжения датчика.
    // Состояния неисправности датчика восстанавливаемые.
    bool faultActive = processFaults(filteredAdc);

    if (!faultActive && systemState != STATE_SENSOR_OPEN_OR_GND &&
        systemState != STATE_SENSOR_SHORT_TO_VCC) {

      // Ждать, пока газовый порог будет превышен непрерывно.
      if (isAlarmOnLevel(filteredAdc)) {
        if (alarmStartMs == 0) {
          alarmStartMs = millis();
        }

        if (millis() - alarmStartMs >= ALARM_CONFIRM_MS) {
          alarmLatched = true;
          setState(STATE_ALARM);
        }
      } else {
        alarmStartMs = 0;
        setState(STATE_NORMAL);
      }
    }
  }

  applyOutputs(systemState);
  updateLed(systemState);

#if DEBUG
  if (millis() - lastDebugMs >= DEBUG_PERIOD_MS) {
    lastDebugMs = millis();
    debugStatus(adcRaw);
#if !LIN_DRIVER
    debugAutocalibrSettings();
#endif
  }
#endif

  serviceDelay(50);
}

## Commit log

2026-07-13 Add KiCad project files
    [Var_LIN.kicad_sch, Датчик утечки газа 2026.kicad_pcb, Датчик утечки газа 2026.kicad_sch]
2026-07-16 Исправление эл.схемы
    [Var_LIN.kicad_sch, Датчик утечки газа 2026.kicad_sch]
2026-07-18 Испаравить вывод в Serial. Добавить вариант LinDriver. Изменить вкл выходов при прогреве
2026-07-18 Корректировать номиналы схемы питания. Uвых=4,7v
    [Var_LIN.kicad_sch, Датчик утечки газа 2026.kicad_sch]
2026-07-18 Разделить платы разных версий
    [Var_LIN.kicad_pcb, Var_LIN.kicad_sch, Датчик утечки газа 2026.kicad_pcb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]
2026-07-19 Добавить в FW реализацию LIN драйвера
    [Датчик утечки газа 2026.kicad_pcb, Датчик утечки газа 2026.kicad_sch]
2026-07-19 Исправление разводки платы Ver_LIN
    [Var_LIN.kicad_pcb, Var_LIN.kicad_sch, Датчик утечки газа 2026.kicad_pcb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]
2026-07-20 Добавить выбор разных режимов поведения OUT в варианте lin_driver
2026-07-20 Дополнить Readme инструкцией прошивки
2026-07-23 Добавлена автокалибровка с записью в EEPROM
2026-08-04 финальная версия 08.2026
    [Var_LIN.kicad_pcb, Датчик утечки газа 2026.kicad_pcb]
2026-09-27 в вер. LIN_DRIVER добавлен контроль замыкания нагрузки
2026-09-27 Оптимизировать GPIO для уменьшения прошивки
2026-09-27 Изменить выходной ключ на умный. Правки печатной платы
2026-10-07 Коррекция ПП. Замена выходной ключ на BTS72002
2026-10-11 Коррекция схемы для драйвера BTS72002EPAXUMA1
2026-10-12 Обновить схемы и логику выходного ключа
